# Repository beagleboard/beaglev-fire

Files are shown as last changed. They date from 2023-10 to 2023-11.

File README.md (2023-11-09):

# BeagleV-Fire

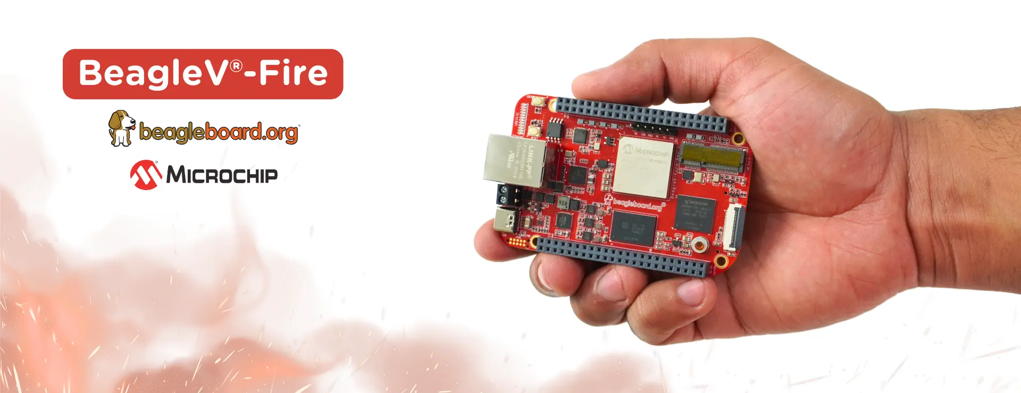
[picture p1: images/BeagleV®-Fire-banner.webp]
BeagleV® Fire banner


BeagleV®-Fire is a revolutionary SBC powered by the Microchip’s PolarFire® MPFS025T System on Chip (SoC) with 4x RV64GC Application cores, 1x RV64IMAC monitor/boot core, and FPGA fabric. BeagleV®-Fire opens up new horizons for developers, tinkerers, and the open-source community to explore the vast potential of RISC-V architecture and FPGA technology. It has the same P8 & P9 cape header pins as BeagleBone Black allowing you to stack your favourite BeagleBone cape on top to expand it’s capability. Built around the powerful and energy-efficient RISC-V instruction set architecture (ISA) along with its versatile FPGA fabric, BeagleV®-Fire SBC offers unparalleled opportunities for developers, hobbyists, and researchers to explore and experiment with RISC-V technology.

## Links

* Terms and conditions: https://docs.beagleboard.org/latest/boards/terms-and-conditions.html
* Documentation: https://docs.beagleboard.org/latest/boards/beaglev/fire
* Design: https://git.beagleboard.org/beaglev-fire/beaglev-fire
* Support: https://forum.beagleboard.org/tags/c/beaglev/15/fire
* Repair: https://www.beagleboard.org/rma
* Purchase: https://beaglev-fire.org

## Goals
* Provide a platform for developing fully open-source SoCs
* Provide solution for low-latency control, such as manufacturing machines
* Long-term availability for education

## Features
* Microchip MPFS025T-FCVG484E RISC-V based Polarfire SoC with 25k logic elements
* BeagleBone AI compatible mechanical footprint, expansion headers, serial header, buttons, LEDs and microSD slot
* 2GB LPDDR4
* 16GB eMMC
* Gigabit Ethernet
* M.2 connector and with daughterboard reference designs
  * 2.4GHz WiFi/Bluetooth using ATWILC3000 and Sub-GHz transceiver using AT86RF212B
  * USB 3 Type-A with SuperSpeed (repurpose PCIe SERDES)
* TagConnect compatible JTAG header footprint
* USB Type-C with SuperSpeed/PCIe, able to provide power
* CSI / Low-speed flexible flat cable (FFC) expansion connector
* [Support for HDMI framer board through Cape headers](https://wiki.seeedstudio.com/BeagleBone_Green_HDMI_Cape/)
* Additional power connector
* [SYZYGY high-speed expansion connector](https://syzygyfpga.io/)

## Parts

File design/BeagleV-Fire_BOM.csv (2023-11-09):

SKU | Description | Manufacturer | MPN | Location | Qty
102110898 | BeagleV - Fire
202003659 | PCBA; BeagleV-Fire |  |  |  | 1
301010000 | SMD RES 0R-5%-1/16W;0402 | YAGEO | RC0402JR-070RL | R51,R53,R66,R67,R69,R102,R151,R182,R186,R220,R221,R234,R235,R254,R262,R264,R265,R273 | 18
301010034 | SMD RES 33R-5%-1/16W;0402 | YAGEO | RC0402JR-0733RL | R159,R214 | 2
301010043 | SMD RES 1M-1%-1/16W;0402 | YAGEO | RC0402FR-071ML | R52,R226,R274,R275,R276,R277,R278,R279 | 8
301010044 | SMD RES 1K-1%-1/16W;0402 | YAGEO | RC0402FR-071KL | R15,R17,R49,R94,R95,R110,R111,R112,R113,R114,R115,R116,R120,R122,R123,R124,R125,R126,R127,R128,R129,R130,R131,R132,R133,R134,R135,R136,R137,R282 | 30
301010047 | SMD RES 10K-1%-1/16W;0402 | YAGEO | RC0402FR-0710KL | R2,R12,R13,R14,R16,R22,R23,R24,R25,R26,R27,R28,R54,R55,R56,R57,R58,R59,R60,R61,R62,R63,R99,R100,R101,R139,R150,R152,R153,R156,R161,R162,R168,R209,R210,R212,R213,R244,R245,R246,R247,R248,R255,R281 | 44
301010050 | SMD RES 510R-5%-1/16W;0402 | YAGEO | RC0402JR-07510RL | R232,R233 | 2
301010051 | SMD RES 51K-1%-1/10W;0402 | Panasonic | ERJ-2RKF5102X | R285 | 1
301010052 | SMD RES 22R-1%-1/16W;0402 | YAGEO | RC0402FR-0722RL | R18,R19,R20,R21 | 4
301010072 | SMD RES 20K-1%-1/16W;0402 | YAGEO | RC0402FR-0720KL | R117 | 1
301010081 | SMD RES 200K-1%-1/16W;0402 | YAGEO | RC0402FR-07200KL | R251 | 1
301010410 | SMD RES 1M-1%-1/4W;1206 | YAGEO | RC1206FR-071ML | R32 | 1
301010444 | SMD RES 10R-1%-1/16W;0402 | YAGEO | RC0402FR-0710RL | R72,R73,R74,R75,R76,R77,R143,R144,R147 | 9
301010456 | SMD RES 100K-1%-1/16W;0402 | YAGEO | RC0402FR-07100KL | R138,R227,R252,R253,R283,R284 | 6
301010457 | SMD RES 49.9K-1%-1/16W;0402 | YAGEO | RC0402FR-0749K9L | R1,R4,R5,R6,R7,R8,R9,R10,R11,R71,R88,R92,R93,R96,R97,R103,R140,R141,R154,R171 | 20
301010524 | SMD RES 100R-±1%-1/20W;0201 | YAGEO | RC0201FR-07100RL | R266,R267,R268,R269,R270,R271,R272 | 7
301010525 | SMD RES 0R-±1%-1/20W;0201 | YAGEO | RC0201FR-070RL | R37,R38,R105,R106,R173,R174 | 6
301010567 | SMD RES 1.5K-1%-1/16W;0402 | YAGEO | RC0402FR-071K5L | R219 | 1
301010633 | SMD RES;4.7K-1%-1/16W-0402 | YAGEO | RC0402FR-074K7L | R176,R177,R178,R187,R191,R192,R215,R216,R217,R218,R222,R223 | 12
301010671 | SMD RES 2.7K-1%-1/16W;0402 | YAGEO | RC0402FR-072K7L | R280 | 1
301010738 | SMD RES 15K-1/16W-1%;0402 | YAGEO | RC0402FR-0715KL | R107 | 1
301010746 | SMD RES 2.2K-1%-1/16W;0402 | YAGEO | RC0402FR-072K2L | R39,R108,R109,R155,R249,R250 | 6
301010783 | SMD RES 82K-1%-1/16W;0402 | YAGEO | RC0402FR-0782KL | R148 | 1
301010856 | SMD RES 2.49K-1%-1/16W;0402 | YAGEO | RC0402FR-072K49L | R118,R175 | 2
301010860 | SMD RES 124K-1%-1/16W;0402 | YAGEO | RC0402FR-07124KL | R146 | 1
301010861 | SMD RES 8.06K-1%-1/16W;0402 | YAGEO | RC0402FR-078K06L | R64 | 1
301011069 | SMD RES 240K-1/16W-1%;0402 | YAGEO | RC0402FR-07240KL | R145 | 1
301011314 | SMD RES 432K-1%-1/16W;0402 | YAGEO | RC0402FR-07432KL | R121 | 1
301011474 | SMD RES 1.1K-1%-1/16W;0402 | YAGEO | RC0402FR-071K1L | R119 | 1
301011475 | SMD RES 240R-1%-1/16W;0402 | YAGEO | RC0402FR-07240RL | R3 | 1
301011477 | SMD RES 27R-1%-1/16W;0402 | YAGEO | RC0402FR-0727RL | R48 | 1
301011831 | SMD RES 105K-1%-1/16W;0402 | YAGEO | RC0402FR-07105KL | R149 | 1
302010000 | SMD CAP Ceramic 33pF-50V-5%-NPO;0402 | YAGEO | CC0402JRNPO9BN330 | C27,C210,C214,C220 | 4
302010004 | SMD CAP Ceramic 100nF-16V-10%-X7R;0402 | YAGEO | CC0402KRX7R7BB104 | C63,C64,C65,C66,C67,C68,C69,C70,C71,C74,C75,C81,C82,C90,C93,C98,C106,C107,C109,C112,C114,C117,C120,C121,C127,C128,C134,C136,C138,C189,C201,C216,C223,C269,C281,C283,C284,C285,C287,C288,C290,C292,C298,C313,C323,C325 | 46
302010006 | SMD CAP Ceramic 10nF-50V-10%-X7R;0402 | YAGEO | CC0402KRX7R9BB103 | C209 | 1
302010010 | SMD CAP Ceramic 470pF-50V-10%-X7R;0402 | YAGEO | CC0402KRX7R9BB471 | C211 | 1
302010012 | SMD CAP Ceramic 100pF-50V-5%-NPO;0402 | YAGEO | CC0402JRNPO9BN101 | C207,C208,C226,C327,C328 | 5
302010016 | SMD CAP Ceramic 18pF-50V-5%-NPO;0402 | YAGEO | CC0402JRNPO9BN180 | C104,C105,C321,C322 | 4
302010024 | SMD CAP Ceramic 100nF-25V-10%-X7R;0402 | YAGEO | CC0402KRX7R8BB104 | C273,C274,C301,C302,C303,C304,C305,C306,C307,C308,C309,C310 | 12
302010027 | SMD CAP Ceramic 27pF-50V-5%-NPO;0402 | YAGEO | CC0402JRNPO9BN270 | C95,C96 | 2
302010039 | SMD CAP Ceramic 2.2nF-25V-10%-X7R;0402 | YAGEO | CC0402KRX7R8BB222 | C217,C218,C225 | 3
302010040 | SMD CAP Ceramic 1uF-10V-10%-X5R;0402 | YAGEO | CC0402KRX5R6BB105 | C77,C110,C111,C196,C197,C198,C199,C202,C215,C224 | 10
302010054 | SMD CAP Ceramic 2.2uF-10V-10%-X7R;0603 | YAGEO | CC0603KRX7R6BB225 | C115 | 1
302010103 | SMD CAP Ceramic 10uF-10V-10%-X5R;0603 | YAGEO | CC0603KRX5R6BB106 | C58,C59,C60,C61,C62,C119,C129,C135,C139,C185,C188,C193,C238,C242,C245,C248,C251,C318,C319,C320 | 20
302010111 | SMD CAP Ceramic 4.7uF-10V-10%-X5R;0603 | YAGEO | CC0603KRX5R6BB475 | C72,C73,C280,C282,C289,C291,C324 | 7
302010146 | SMD CAP Ceramic 4.7uF-25V-10%-X5R;0805 | YAGEO | CC0805KKX5R8BB475 | C1,C203,C219,C312 | 4
302010166 | SMD CAP Ceramic 47uF-6.3V-20%-X5R;0805 | YAGEO | CC0805MKX5R5BB476 | C146,C147,C157,C168,C169,C172,C178,C183,C194,C195,C230,C236,C259 | 13
302010235 | SMD CAP Ceramic 22uF-25V-20%-X5R;0805 | YAGEO | CC0805MKX5R8BB226 | C113,C116,C190,C191,C192,C200,C204,C205,C221,C222,C314 | 11
302010270 | SMD CAP Ceramic;1uF-6.3V-±20%-X5R;0201 | YAGEO | CC0201MRX5R5BB105 | C154,C155,C156 | 3
302010271 | SMD CAP Ceramic 100nF-10V-10%-X5R;0201 | YAGEO | CC0201KRX5R6BB104 | C2,C3,C4,C5,C6,C7,C8,C9,C10,C11,C12,C13,C14,C15,C16,C17,C18,C19,C20,C21,C22,C23,C24,C25,C26,C28,C29,C30,C31,C32,C33,C34,C35,C36,C37,C38,C39,C40,C41,C42,C43,C44,C45,C46,C48,C49,C50,C51,C52,C53,C54,C55,C56,C57,C85,C86,C87,C88,C132,C133,C144,C145,C151,C152,C153,C167,C171,C176,C177,C180,C184,C187,C206,C228,C229,C234,C235,C237,C239,C240,C241,C243,C244,C246,C247,C249,C250,C252,C257,C258,C260 | 91
302010389 | SMD CAP Ceramic 1nF-16V-10%-X7R;0201 | YAGEO | CC0201KRX7R7BB102 | C170,C173,C179,C186,C231,C232,C253 | 7
302010394 | SMD CAP Ceramic 1nF-50V-5%-X7R;0402 | YAGEO | CC0402JRX7R9BB102 | C91,C212,C213,C270 | 4
302010423 | SMD CAP Ceramic;47nF-6.3V-10%-X5R;0201 | YAGEO | CC0201KRX5R5BB473 | C148,C149,C150 | 3
302010426 | SMD CAP 2.2nF-10V-10%-X7R;0201 | YAGEO | CC0201KRX7R6BB222 | C140,C141 | 2
302010726 | SMD CAP Ceramic 3.3nF-25V-10%-X7R;0201 | Murata | GRM033R71E332KA12D | C254 | 1
302010727 | SMD CAP Ceramic 4.7nF-10V-10%-X7R;0201 | YAGEO | CC0201KRX7R6BB472 | C165,C181,C227,C233,C255 | 5
302010746 | SMD CAP Ceramic;6.8pF-50V-0.25pF-C0G-0402 | Murata | GRM1555C1H6R8CA01D | C311 | 1
302010747 | SMD CAP Ceramic 100uF-10V-20%-X5R;1206 | TDK | C3216X5R1A107M160AC | C108 | 1
302011831 | SMD CAP Ceramic 10nF-6.3V-10%-X5R;0201 | Yageo | CC0201KRX5R5BB103 | C142,C143,C160,C161,C162,C163,C164,C166,C174,C175,C182,C256 | 12
302011962 | SMD CAP Ceramic 1nF-2kV-10%-X7R;1206 | YAGEO | CC1206KKX7RDBB102 | C83 | 1
302020469 | SMD CAP Tantalum 330uF-2.5V;B | KEMET | T520B337M2R5ATE070 | C158,C159 | 2
303010128 | SMD Inductor 2.2uH-20%-1.3A;2P-2520 | Murata | LQM2HPN2R2MG0L | L5 | 1
303010172 | SMD Innductor 0.47uH-20%;L2.0*W1.6*H1.0mm | Sunlord | WPN201610MR47MT | L2,L3,L4 | 3
303011528 | SMD Power Inductor 0.56uH-20%-9.3A;2P-4.4*4.4*1.9MM | CODACA | CSHB0421-R56M | L1 | 1
303011879 | SMD Inductor 1.0uH-20%-7A;L4.2*W4.4*H2.0mm | Sunlord | MWSA0402S-1R0MT | L6 | 1
303030040 | SMD Ferrite Bead 120R-1.3A;0402 | Murata | BLM15PD121SN1D | FB3,FB4 | 2
304011072 | SMD Diode Schottky 30V-200mA;SOD-523 | LRC | LRB520S-30T1G | D15,D16,D17 | 3
304050002 | SMD Diode TVS 5V-600W;DO-214AA | ST | SMBJ5.0CA-TR | D8 | 1
304051161 | SMD Diode TVS 24VWM 29.5V;SMB | Brightking | SMBJ24CA(Brightking) | D25 | 1
304060074 | SMD Diode ESD 0.05pF;0402 | SEMITEL | ESDPSA0402V05 | D3,D4,D5,D6,D7,D9,D10,D11,D12,D13,D14,D18,D19 | 13
304060294 | SMD Diode Array ESD;4 Channel | TI | TPD4E05U06DQAR | D1,D2 | 2
304090075 | SMD LED Clear-Blue;0402 | Bright | BL-HB337A-AV-TRB | LED3,LED4,LED5,LED6,LED7,LED8,LED9,LED10,LED11,LED12,LED13,LED14 | 12
304090121 | SMD LED Clear-Green;0402 | Bright | BL-HGE37A-AV-TRB | LED1 | 1
305020002 | SMD Transistors PNP 40V-200mA;SOT-23 | ON | MMBT3906LT3G | Q30 | 1
305030659 | SMD MOSFET N-CH 20V -630MA ；SOT-523 | Diodes | DMG1012T-7 | Q3,Q4,Q5,Q6,Q7,Q8,Q9,Q10,Q11,Q12,Q13,Q14,Q15,Q16,Q19,Q20,Q24,Q25,Q27,Q28 | 20
305031179 | SMD MOSFET P-CH 30V-12A;HSMT8 | Rohm | RQ3E120ATTB | Q1,Q17,Q29,Q31 | 4
305050191 | SMD Transistor Array 2PNP 45V-0.1A;SOT36 | Diodes Incorporated | BCM857BS-7-F | Q18,Q2 | 2
306011049 | SMD Crystal;25MHz-18pF-20ppm;SMD-2520-4P-L2.5*W2.0*H0.6mm | Interquip | 5ZAA25000182TFA0Q3 | X1 | 1
306011142 | SMD Crystal 27MHZ-12PF-30ppm;4P-L2.5*W2.0*H0.6mm | Interquip | 5ZAA27000121TF60Q3 | X2 | 1
306011268 | SMD Crystal 25MHz-12pF-10ppm-30ppm-50R;4P-SMD-L3.2*W2.5*H0.8mm | Interquip | 5YAA25000121TF50Q3 | X3 | 1
306020621 | SMD Oscillator;32.768KHz-3.3V-30ppm;SMD-2520-4P-L2.5*W2.0*H0.95mm | Interquip | 1651-L3273-BTBQYA | OSC1 | 1
306020701 | SMD Oscillator;125MHz-10ppm-6P-3.2*2.5mm | Microchip | DSC1123CI5-125.0000 | U7 | 1
310011580 | SMD IC PHY;10/100/1000 Ethernet Physical Layer Transceiver With RGMIII and SGMII;QFN-48 | Realtek | RTL8211FS-CG | U28 | 1
310030211 | SMD IC PMIC;MSOP-8 | TI | TPS2051BDGNR | U10 | 1
310031388 | SMD IC PMIC; IC VREF SHUNT ADJ;SOT23-3 | TI | ATL431AIDBZR | U39 | 1
310031449 | SMD IC PMIC;SOT23-5 | TI | TLV62569DBVT | U36 | 1
310032350 | SMD IC PMIC;10A-QFN-32 | Microchip | MIC22950YML-TR | U13 | 1
310032351 | SMD IC PMIC LDO-3.3V-150mA;SOT-23A | Microchip | MCP1754ST-3302E/CB | U16 | 1
310032353 | SMD IC PMIC;3A-DFN-12 | Microchip | MIC23303YML-TR | U18,U19,U20 | 3
310032372 | SMD IC PMIC LDO-ADJ-500mA;DFN-8 (2x3mm) | Microchip | MCP1725T-ADJE/MC | U17 | 1
310050078 | SMD IC Logic;US8(8-VFSOP | TI | SN74LVC2G241DCUR | U21 | 1
310051370 | SMD IC Logic;4-Bit Bidirectional Voltage-Level Translator;DSBGA-12 | Union Semiconductor | UM3304 | U30,U31,U32,U33,U34,U35 | 6
310071169 | SMD IC Interface;QFN-32 | Microchip | USB3340-EZK-TR | U8 | 1
310071170 | SMD IC Controller;X2QFN12 | NXP | PTN5150AHXMP | U9 | 1
310091085 | SMD IC Memory;16GB eMMC 5.1;VFBGA-153 | Kingston | EMMC16G-TB29-PZ90 | U3 | 1
310091104 | SMD IC Memory;SOIC-8 | Winbond | W25Q128JVSIQ | U4 | 1
310091347 | SMD IC Memory;32Kb-IIC Serial EEPROM;SOT23-5 | FMD | FT24C32A-ELRT | U22 | 1
310091407 | SMD IC Memory;LPDDR4 2GB(16bits x 2 channels) 1866MHz 3733Mbps;FBGA-200 (10X15) | Samsung | K4F6E3S4HM-MGCJ | U2 | 1
310100567 | SMD IC ADC 16-BIT SPI;UQFN-20 | Microchip | MCP3464RT-E/NC | U11 | 1
310110523 | SMD IC Clock;PCI-Express Gen 2 Dual Output 100MHz Clock Generator;TDFN-10 | Skyworks | Si52112-B3-GM2 | U38 | 1
310990589 | SMD IC REG LINEAR 2.5V 300MA;SOT23-5 | Microchip | MIC5504-2.5YM5-TR | U14 | 1
310991057 | SMD IC FPGA SoC;FCVG-484 | Microchip | MPFS025T-FCVG484E | U1 | 1
311020518 | SMD Top Button 1.57N;4P-L4.6*W3.2*H2.5mm | ALPS | SKRPABE010 | SW1,SW2 | 2
319015079 | PCB;BeagleV-Fire Rev A-Red-12 Layers |  |  |  | 1
320010943 | SMD USB Type-c;12P+4-8.9*7.3*3.2mm | MTCONN | UBF31-0171 | J5 | 1
320020078 | DIP Black Male Header VERT;1*6P-2.54-2.5-11.5/3.0mm | Sinotop | ST-PH-254-0087-1*6P-6T | J6 | 1
320030424 | DIP Black Female Header;2*23P-2.54*8.5-3.0mm | Sinotop | FF-1236 | P8,P9 | 2
320060764 | SMD FPC CONN;22P-0.5mm-90D-Bottom Contact-L15.40*W5.25*H2.00mm | BEST | 0.5K-DX-22PWB | J7 | 1
320090416 | SMD SD Card Holder;Reverse-Bottom | YU LIANG | YL004-030-001 | J2 | 1
320111630 | SMD Connector Black m.2 E-key;67P-0.5mm | FOXCONN | AS0BC27-S40BE-7H | J9 | 1
320111970 | DIP Female Screw Terminal;2P-3.5mm-Black | Sinotop | STP128-350-2P | J1 | 1
320140517 | DIP RJ45;1000M | LINK-PP | LPJG0933H11NL | J4 | 1
320210541 | SMD BTB Female CONN;With High Speed Differential Pair and 2*20P+2P-0.5mm;L21.27*W7.49*H3.25mm | Samtec | QSH-020-01-F-D-DP-A-K-TR | J8 | 1
326050927 | SMD Stud;M2铜柱 | FOXCONN | 2E0BC21-A40TP-7H | MH4 | 1

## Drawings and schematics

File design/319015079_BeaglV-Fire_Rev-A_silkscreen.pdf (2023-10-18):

# Ethernet LED(14-3) USB JTAG

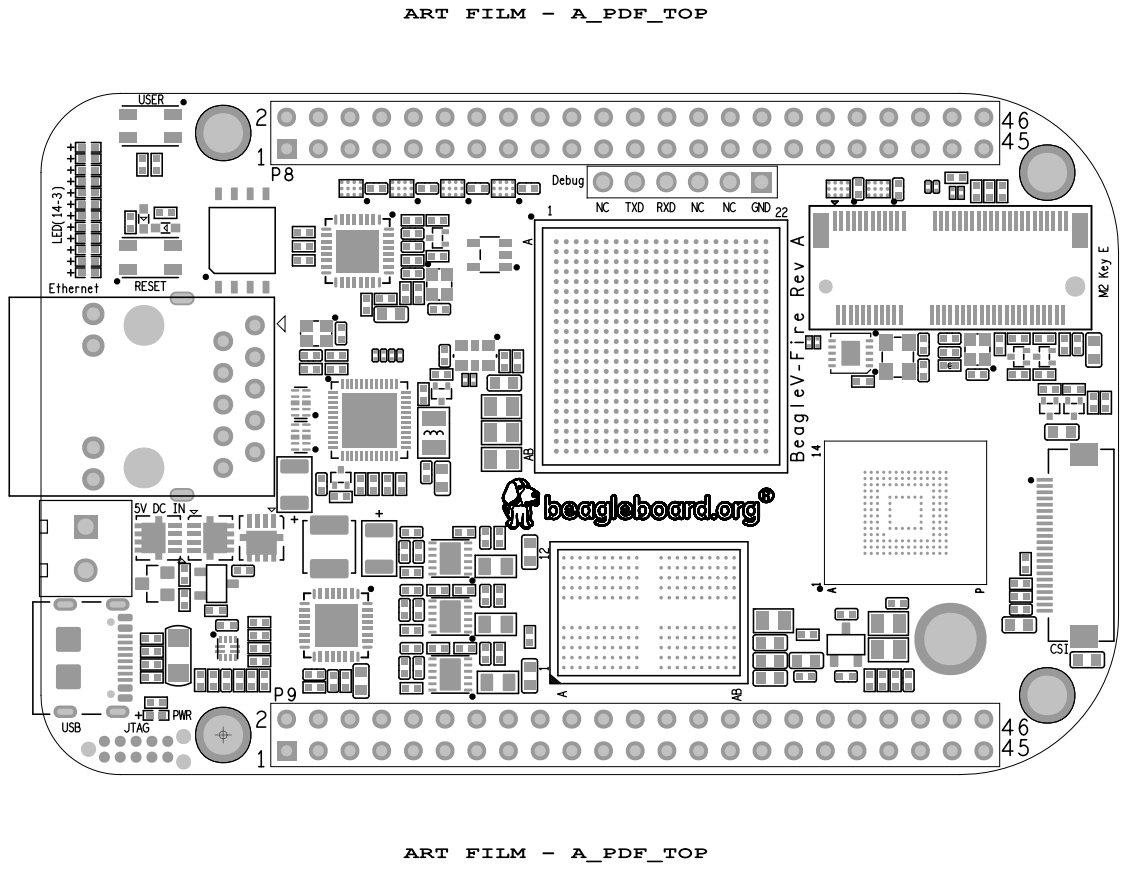
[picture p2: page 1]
ART FILM - A_PDF_TOP; RESET; PWR; USER; Debug; NC GND22; CSI; M2 Key E

NC TXD RXD NC

BeagleV-Fire Rev A

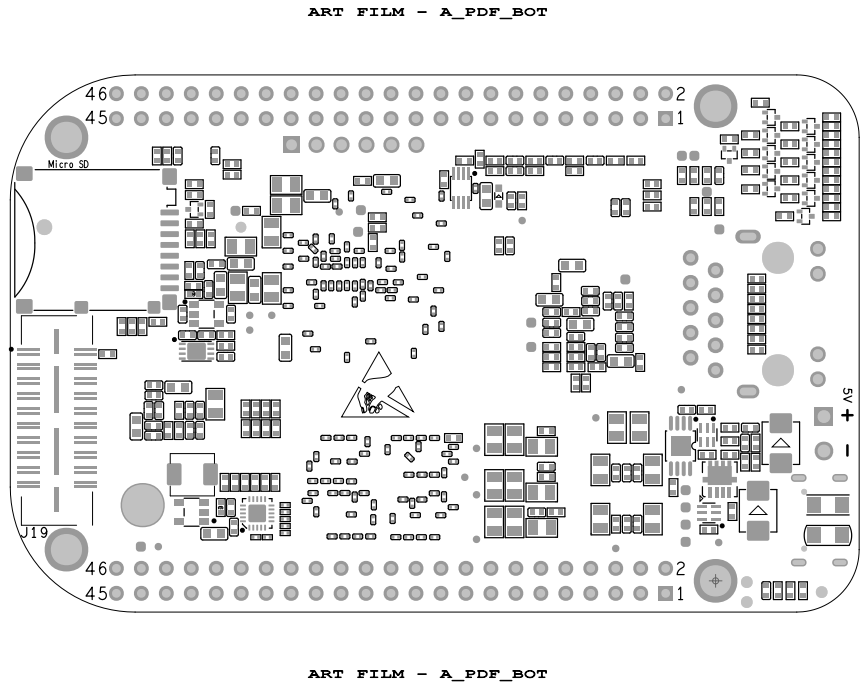
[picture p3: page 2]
ART FILM - A_PDF_BOT; Micro SD

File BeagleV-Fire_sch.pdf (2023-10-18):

# Power Supply

# Revision History

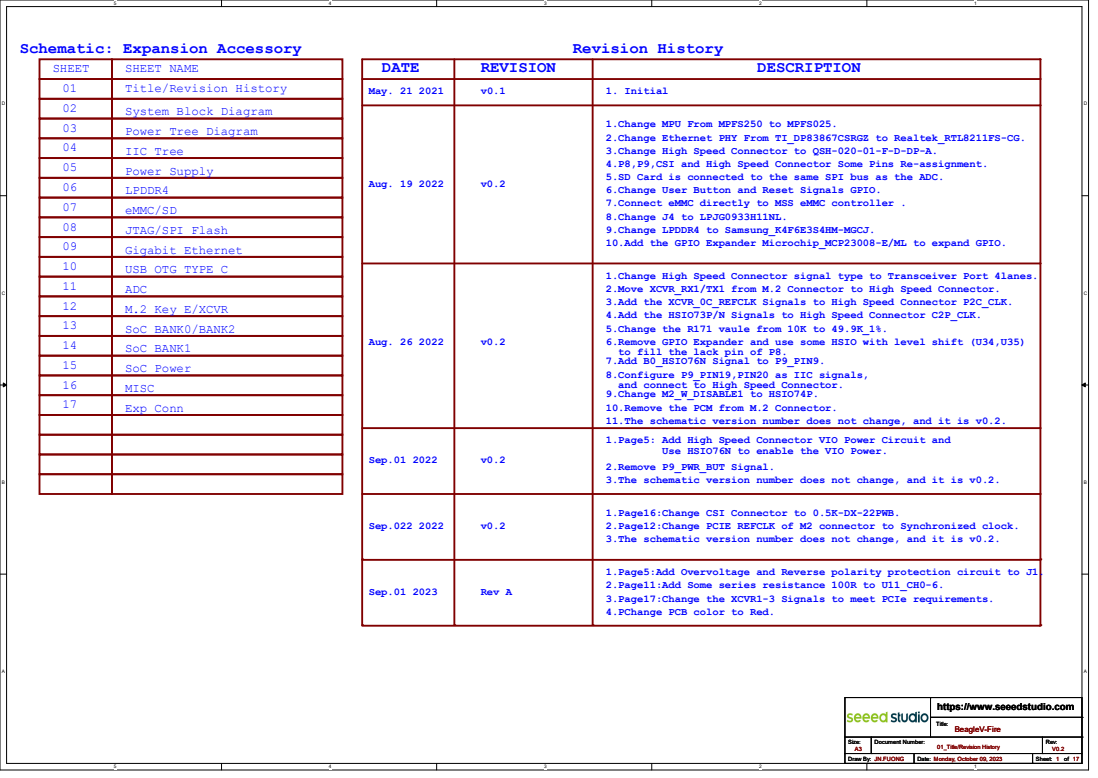
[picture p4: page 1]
May. 21 2021; 1. Initial; Schematic: Expansion Accessory; DATE; REVISION; DESCRIPTION; SHEET; Aug. 19 2022; Aug. 26 2022; 17 Exp Conn; Sep.01 2022; 4.PChange PCB color to Red.; Title: Size:; Document Number:; Rev: Draw By:; Date:; Sheet:; https://www.seeedstudio.com A3; JN.FUONG; Monday, October 09, 2023; BeagleV-Fire 01_Title/Revision History Title: Size:

SHEET NAME
Title/Revision History
System Block Diagram
Power Tree Diagram
IIC Tree

1.Change MPU From MPFS250 to MPFS025.
2.Change Ethernet PHY From TI_DP83867CSRGZ to Realtek_RTL8211FS-CG.
3.Change High Speed Connector to QSH-020-01-F-D-DP-A.
4.P8,P9,CSI and High Speed Connector Some Pins Re-assignment.
5.SD Card is connected to the same SPI bus as the ADC.
6.Change User Button and Reset Signals GPIO.
7.Connect eMMC directly to MSS eMMC controller .
8.Change J4 to LPJG0933H11NL.
9.Change LPDDR4 to Samsung_K4F6E3S4HM-MGCJ.
10.Add the GPIO Expander Microchip_MCP23008-E/ML to expand GPIO.

LPDDR4
eMMC/SD
JTAG/SPI Flash
Gigabit Ethernet
USB OTG TYPE C
ADC
M.2 Key E/XCVR
SoC BANK0/BANK2
SoC BANK1
SoC Power
MISC

1.Change High Speed Connector signal type to Transceiver Port 4lanes.
2.Move XCVR_RX1/TX1 from M.2 Connector to High Speed Connector.
3.Add the XCVR_0C_REFCLK Signals to High Speed Connector P2C_CLK.
4.Add the HSIO73P/N Signals to High Speed Connector C2P_CLK.
5.Change the R171 vaule from 10K to 49.9K_1%.
6.Remove GPIO Expander and use some HSIO with level shift (U34,U35)
to fill the lack pin of P8.
7.Add B0_HSIO76N Signal to P9_PIN9.
8.Configure P9_PIN19,PIN20 as IIC signals,
and connect to High Speed Connector.
9.Change M2_W_DISABLE1 to HSIO74P.
10.Remove the PCM from M.2 Connector.
11.The schematic version number does not change, and it is v0.2.
1.Page5: Add High Speed Connector VIO Power Circuit and

Use HSIO76N to enable the VIO Power.

2.Remove P9_PWR_BUT Signal.
3.The schematic version number does not change, and it is v0.2.

Sep.022 2022 | v0.2 | 1.Page16:Change CSI Connector to 0.5K-DX-22PWB. 2.Page12:Change PCIE REFCLK of M2 connector to Synchronized clock. 3.The schematic version number does not change, and it is v0.2.

Sep.01 2023 | Rev A | 1.Page5:Add Overvoltage and Reverse polarity protection circuit to J1. 2.Page11:Add Some series resistance 100R to U11_CH0-6. 3.Page17:Change the XCVR1-3 Signals to meet PCIe requirements.

BeagleV-Fire 01_Title/Revision History

# 8CH ADC

MIPI CSI | BeagleBoard headers

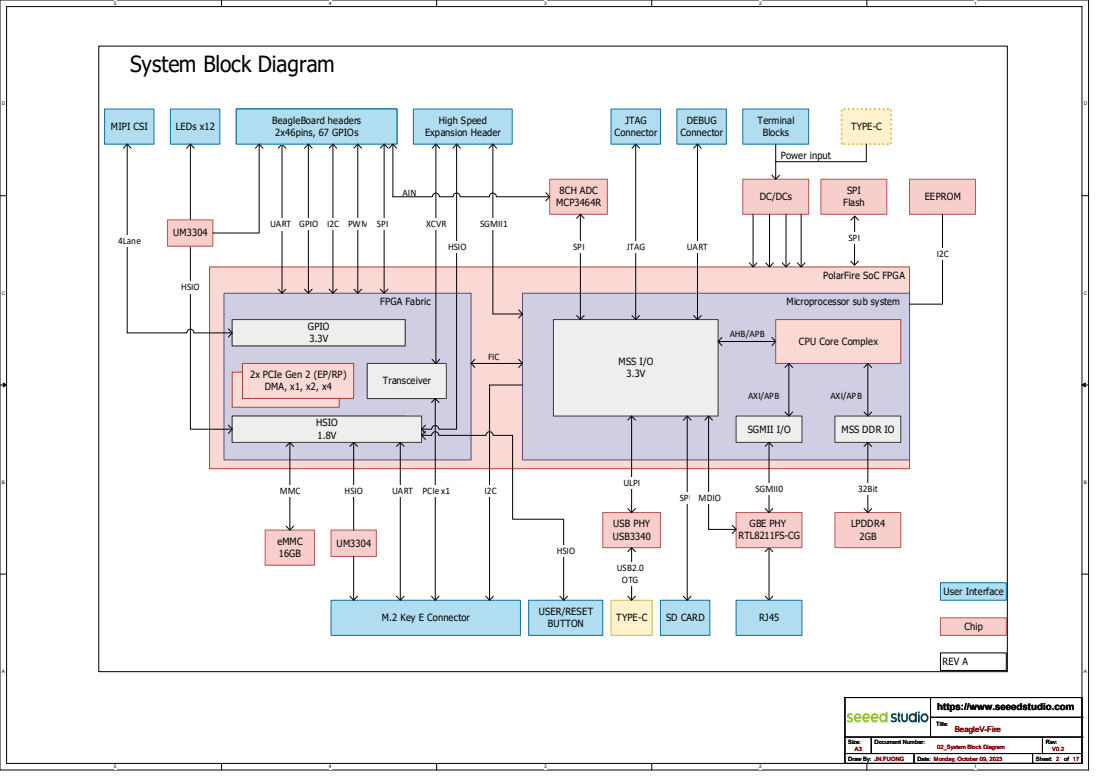
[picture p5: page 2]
SGMII I/O; MSS I/O 3.3V; LPDDR4 2GB; GBE PHY RTL8211FS-CG; USB PHY USB3340; TYPE-C; MCP3464R; HSIO; GPIO; FPGA Fabric; 2x46pins, 67 GPIOs; Transceiver; High Speed Expansion Header; eMMC 16GB; HSIO 1.8V; GPIO 3.3V; DC/DCs; Terminal; Blocks LEDs x12; JTAG Connector; DEBUG Connector; User Interface; Chip; REV A; 4Lane; BeagleBoard headers 2x46pins, 67 GPIOs; MMC; UART; XCVR; SGMII1; PCIe x1; FIC; AIN; SPI; JTAG; Power input; USB2.0 OTG; ULPI; SPI MDIO; SGMII0; 32Bit; AHB/APB; AXI/APB; SPI Flash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

System Block Diagram

GPIO I2C PWM SPI
UART

PolarFire SoC FPGA

Microprocessor sub system

CPU Core Complex

2x PCIe Gen 2 (EP/RP)
DMA, x1, x2, x4

MSS DDR IO

BUTTON M.2 Key E Connector

SD CARD USER/RESET

BeagleV-Fire 02_System Block Diagram

Reverse & OVP | USB_5V | SYS_5V

## VDD_5V

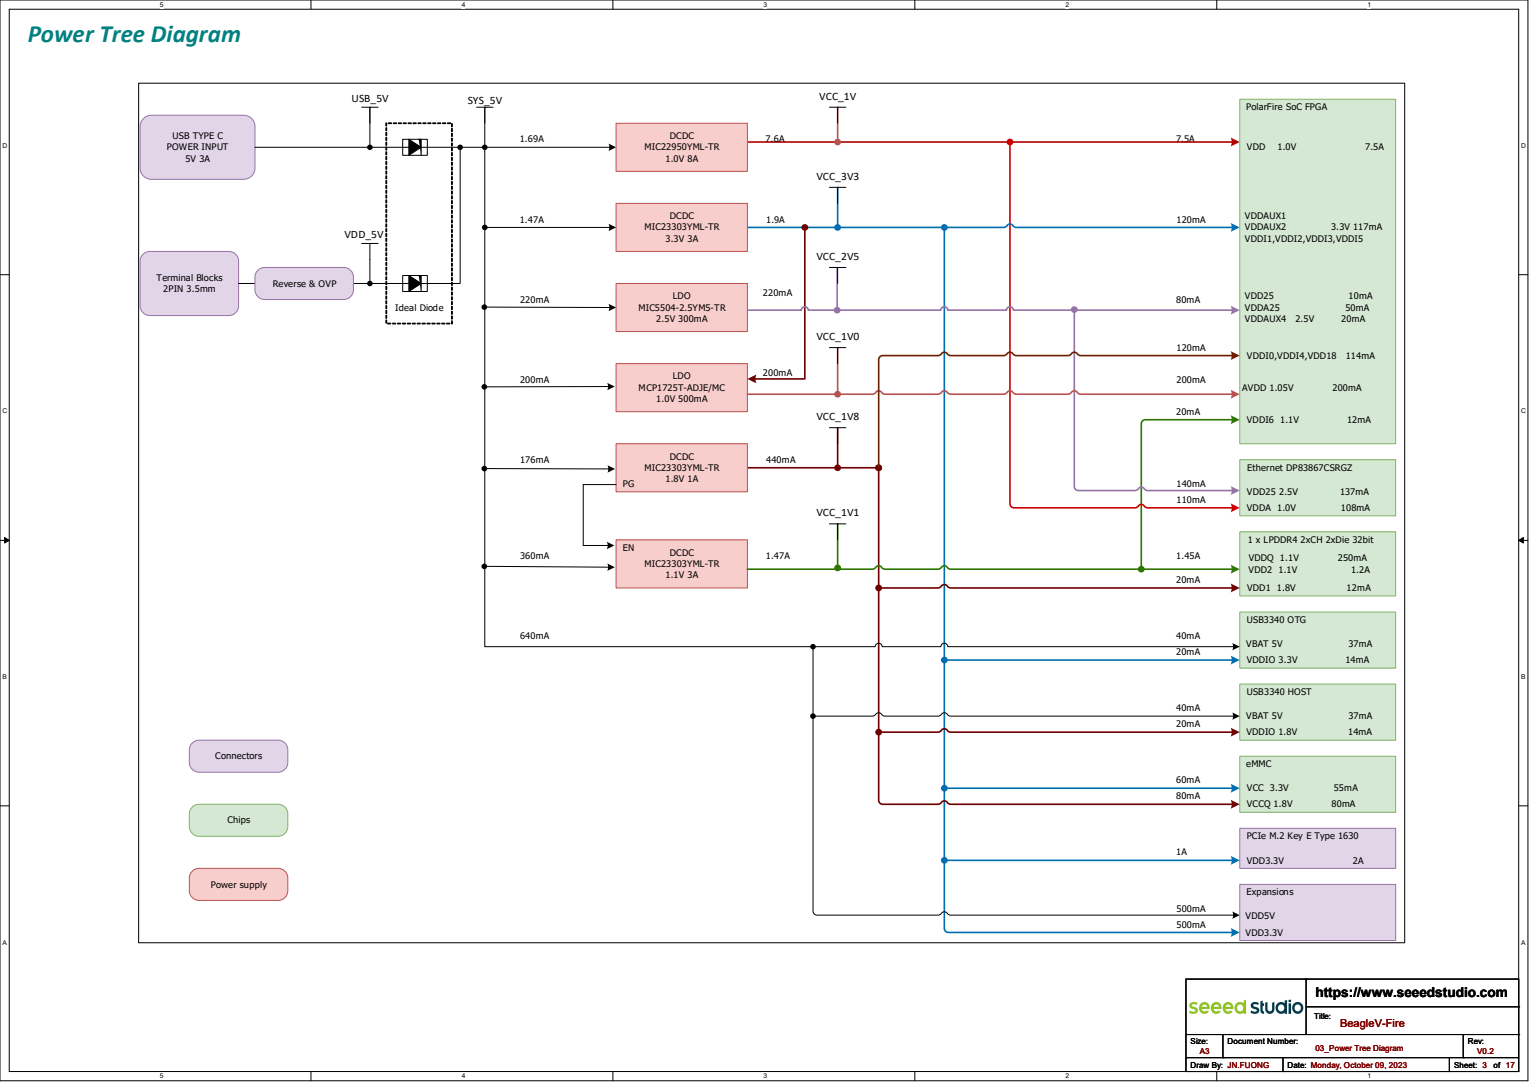
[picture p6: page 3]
USB TYPE C POWER INPUT 5V 3A; VDD 1.0V; VDDI0,VDDI4,VDD18 114mA; VDDAUX1 VDDAUX2; VDDI1,VDDI2,VDDI3,VDDI5 AVDD 1.05V; VDDI6 1.1V; 1 x LPDDR4 2xCH 2xDie 32bit VDDQ 1.1V; 250mA VDD2 1.1V; VDD1 1.8V; Ethernet DP83867CSRGZ VDDA 1.0V; VDD25 2.5V; 137mA USB3340 OTG; VBAT 5V; eMMC; VCC 3.3V; Expansions VDD5V VDD3.3V VCCQ 1.8V; VDD25; VDDA25; VDDAUX4 2.5V; VDDIO 3.3V; 14mA USB3340 HOST VBAT 5V; VDDIO 1.8V; PCIe M.2 Key E Type 1630 VDD3.3V; DCDC MIC22950YML-TR; 1.0V 500mA DCDC MIC23303YML-TR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

Power Tree Diagram

PolarFire SoC FPGA

LDO MCP1725T-ADJE/MC

BeagleV-Fire 03_Power Tree Diagram

# EEPROM ADDR:0x50

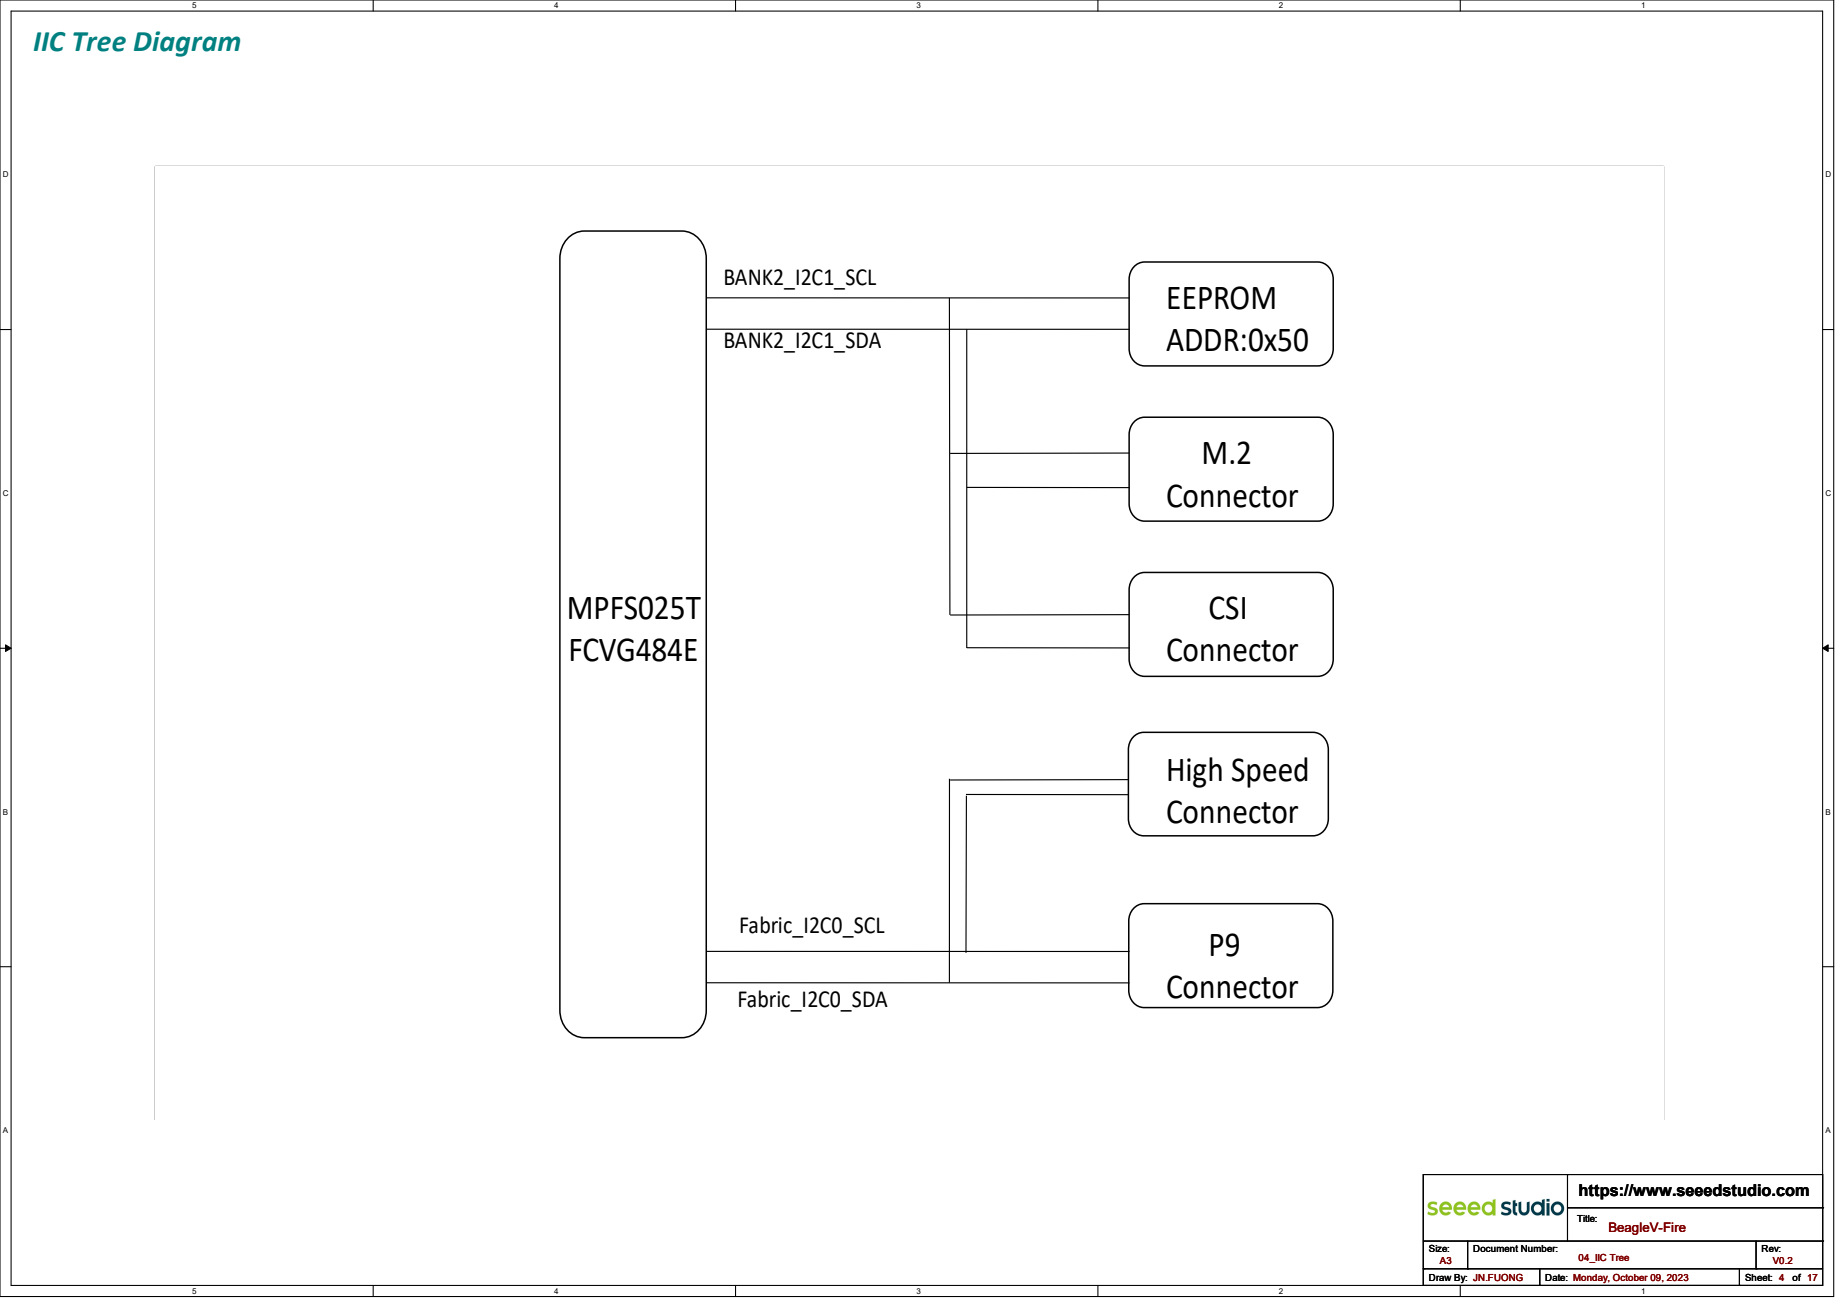
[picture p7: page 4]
MPFS025T FCVG484E; M.2 Connector; CSI Connector; High Speed Connector; P9 Connector; BANK2_I2C1_SCL; BANK2_I2C1_SDA; Fabric_I2C0_SDA; Fabric_I2C0_SCL; https://www.seeedstudio.com A3; JN.FUONG; Monday, October 09, 2023; BeagleV-Fire 04_IIC Tree Title: Size:; Document Number:; Rev: Draw By:; Date:; Sheet:

IIC Tree Diagram

BeagleV-Fire 04_IIC Tree

# VCC_3V3

# 50V Q2B

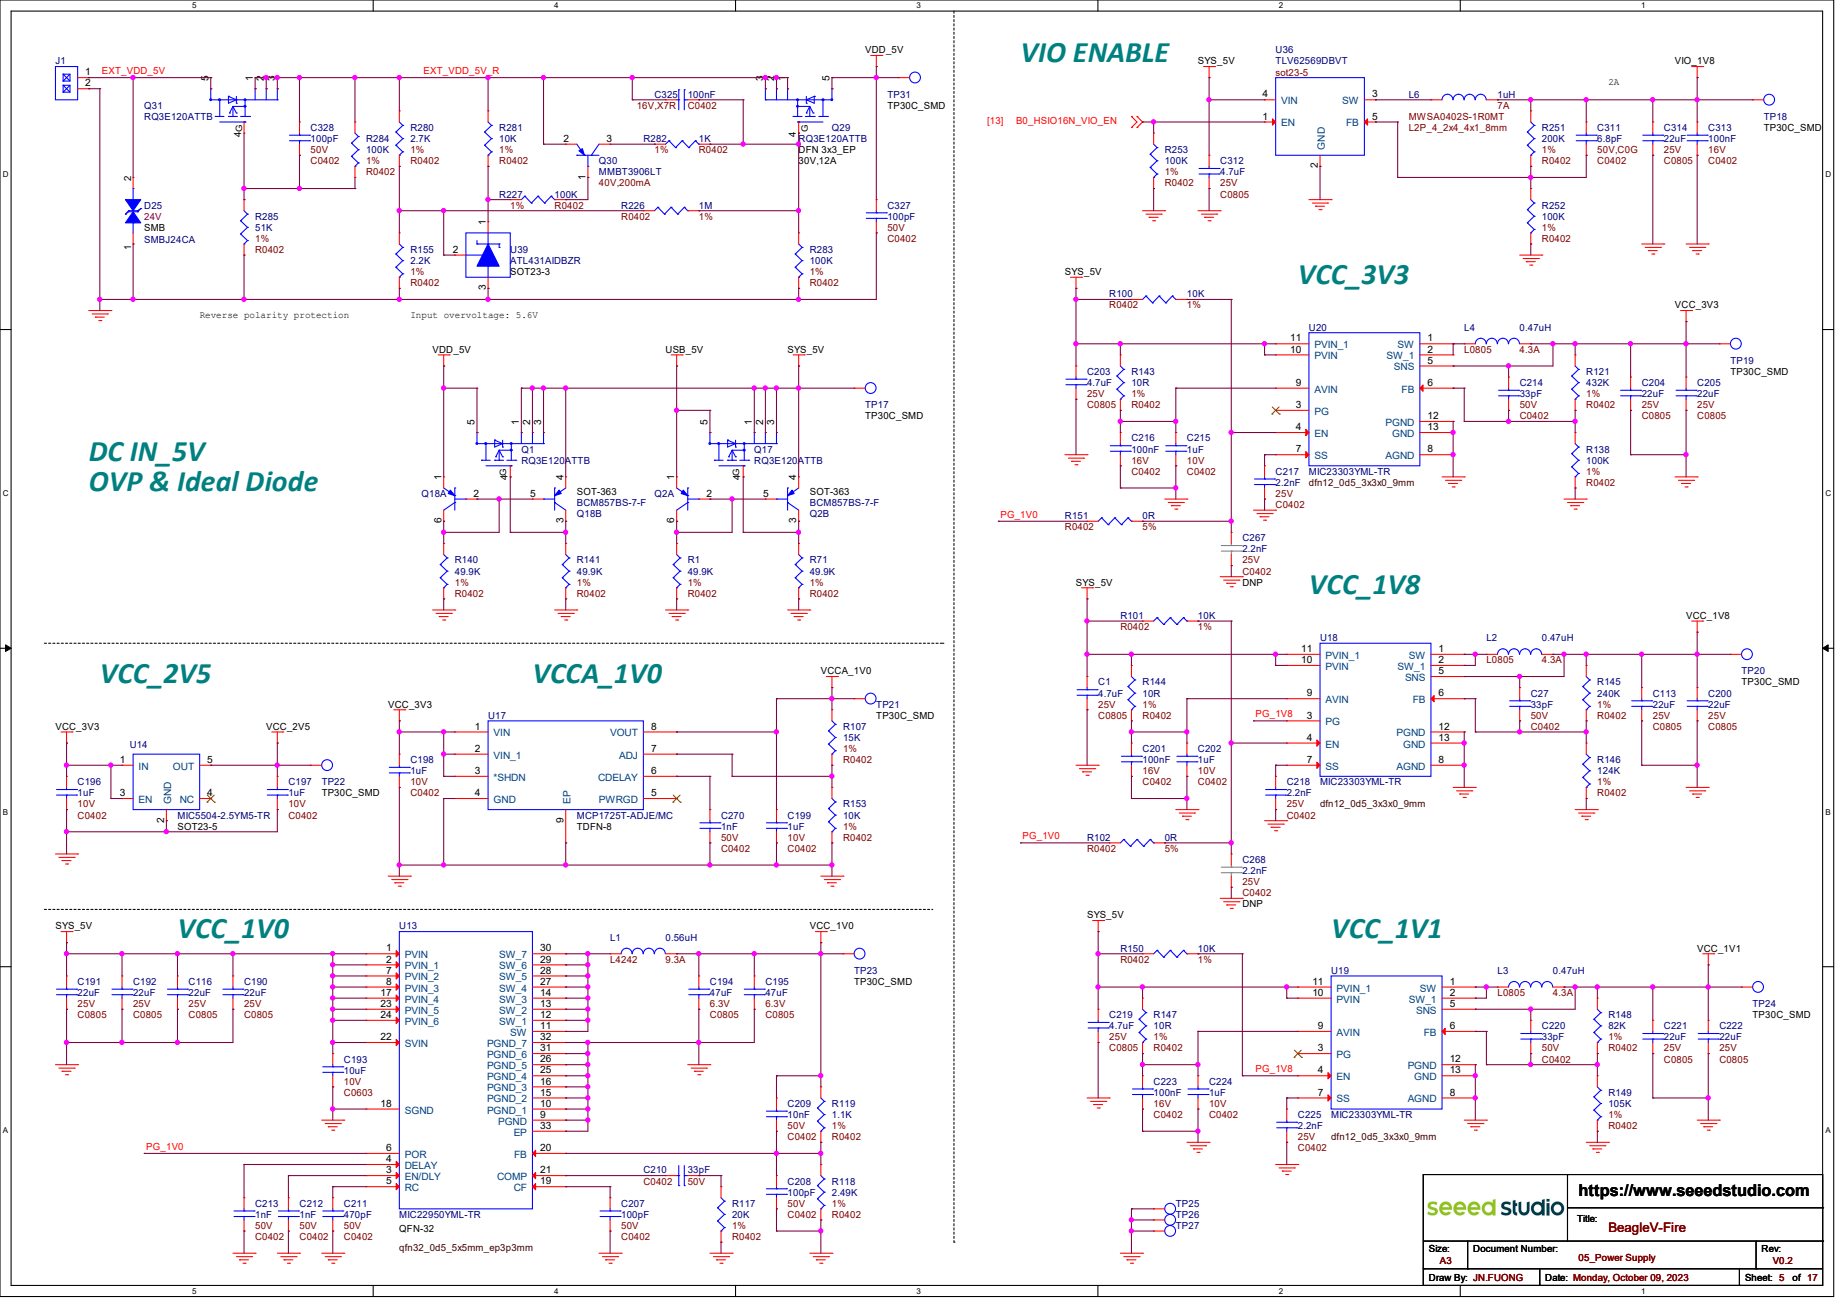
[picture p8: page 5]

# LPDDR4_CONNECTION

# VCC_1V1 VCC_1V8

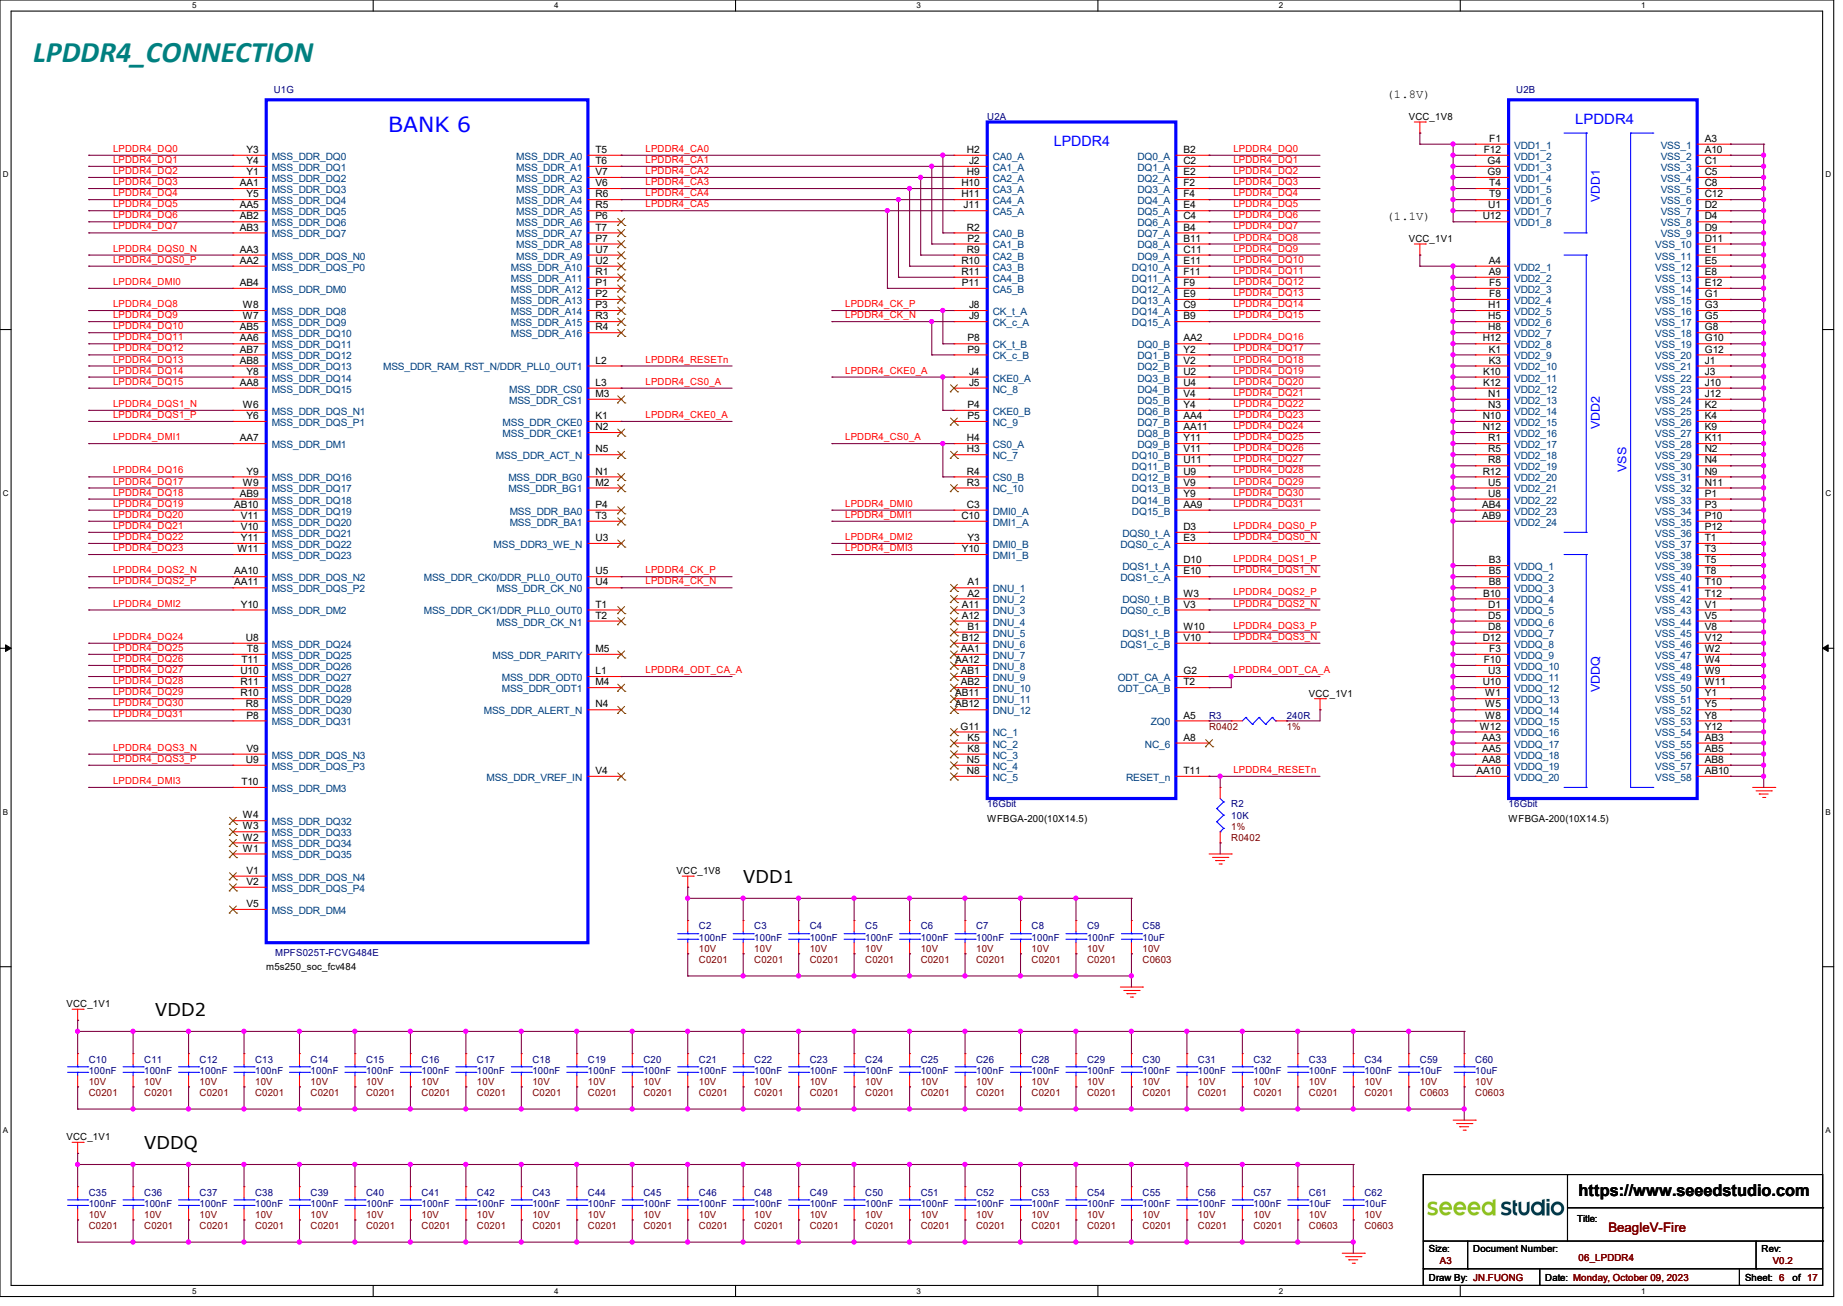
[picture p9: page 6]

# eMMC/SD

# eMMC

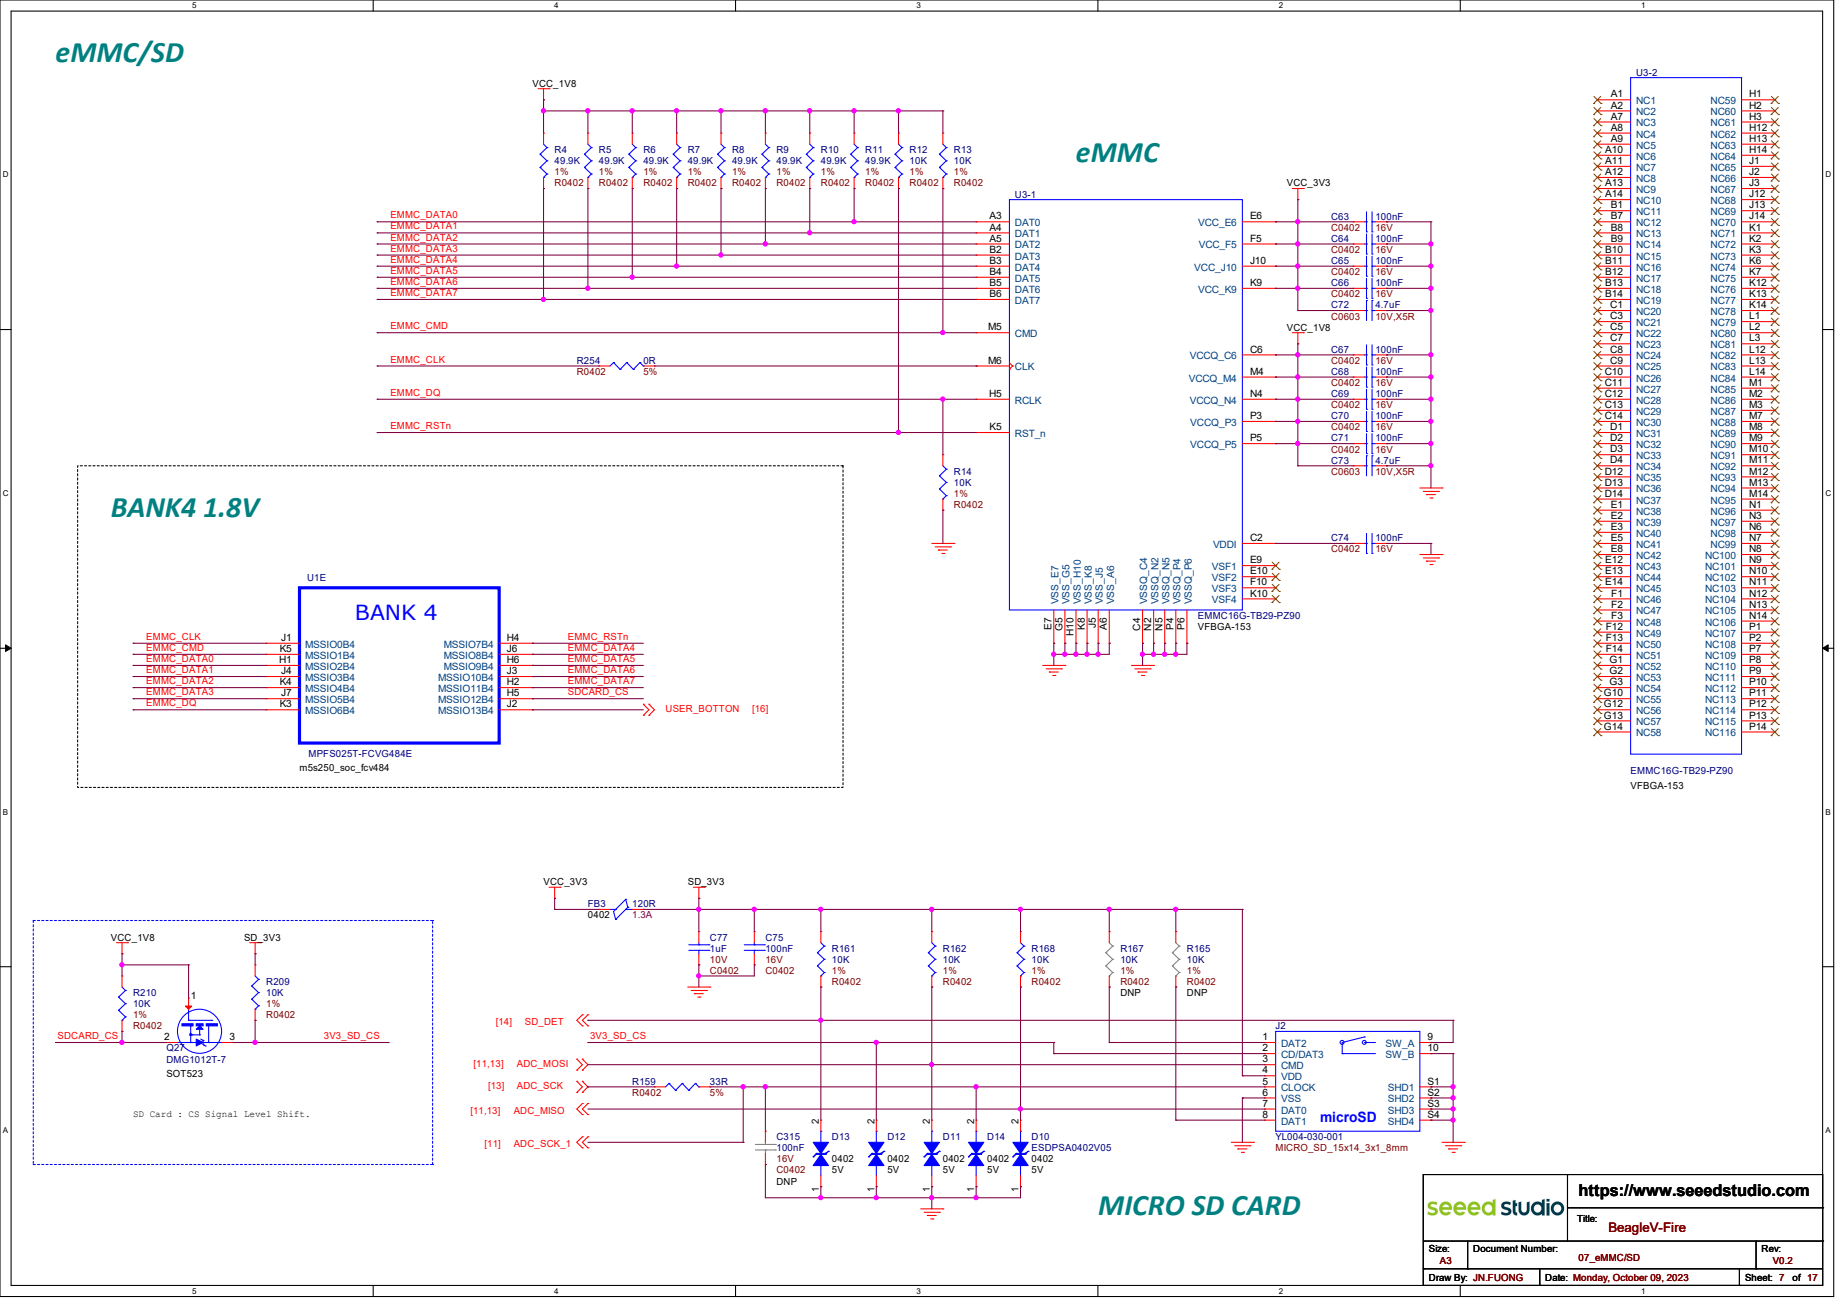
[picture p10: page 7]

MICRO SD CARD SD Card : CS Signal Level Shift.
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

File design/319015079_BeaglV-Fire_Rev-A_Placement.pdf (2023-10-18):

# ART FILM - ASSEM_TOP

# C274 U31C215

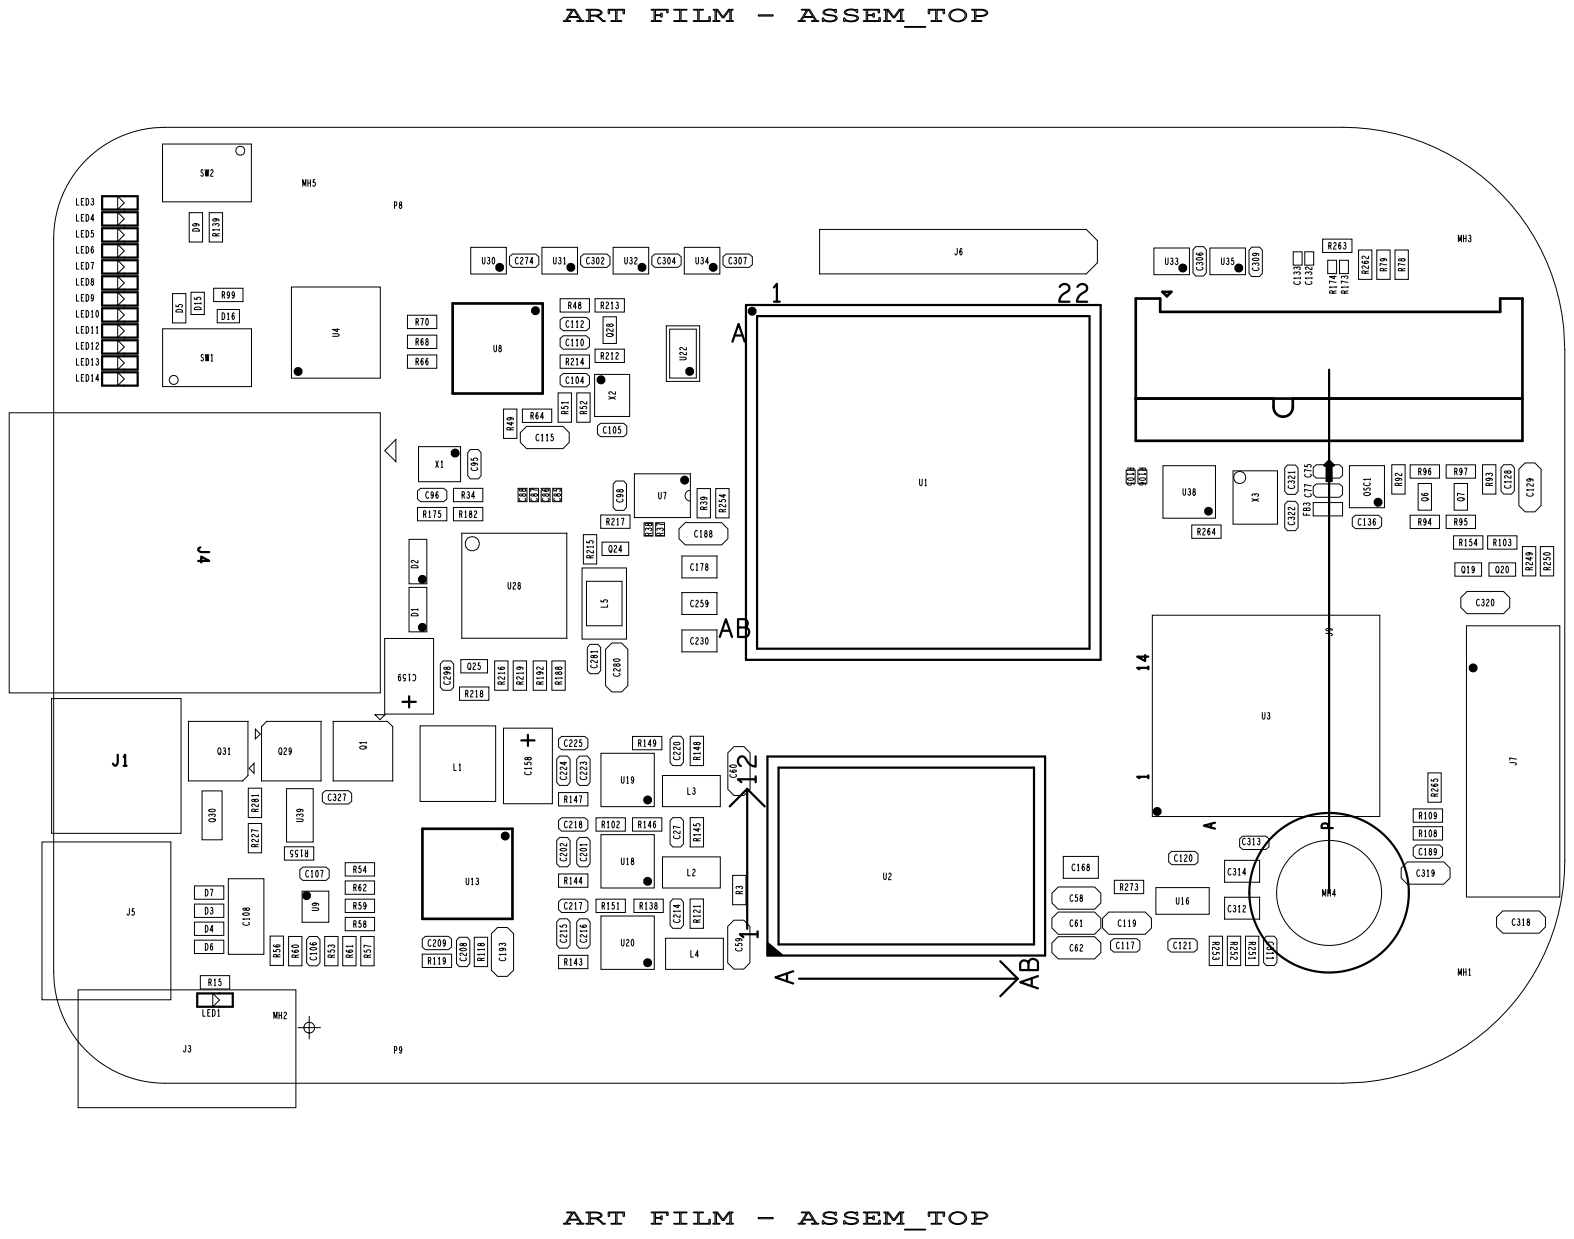
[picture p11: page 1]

# ART FILM - ASSEM_BOT

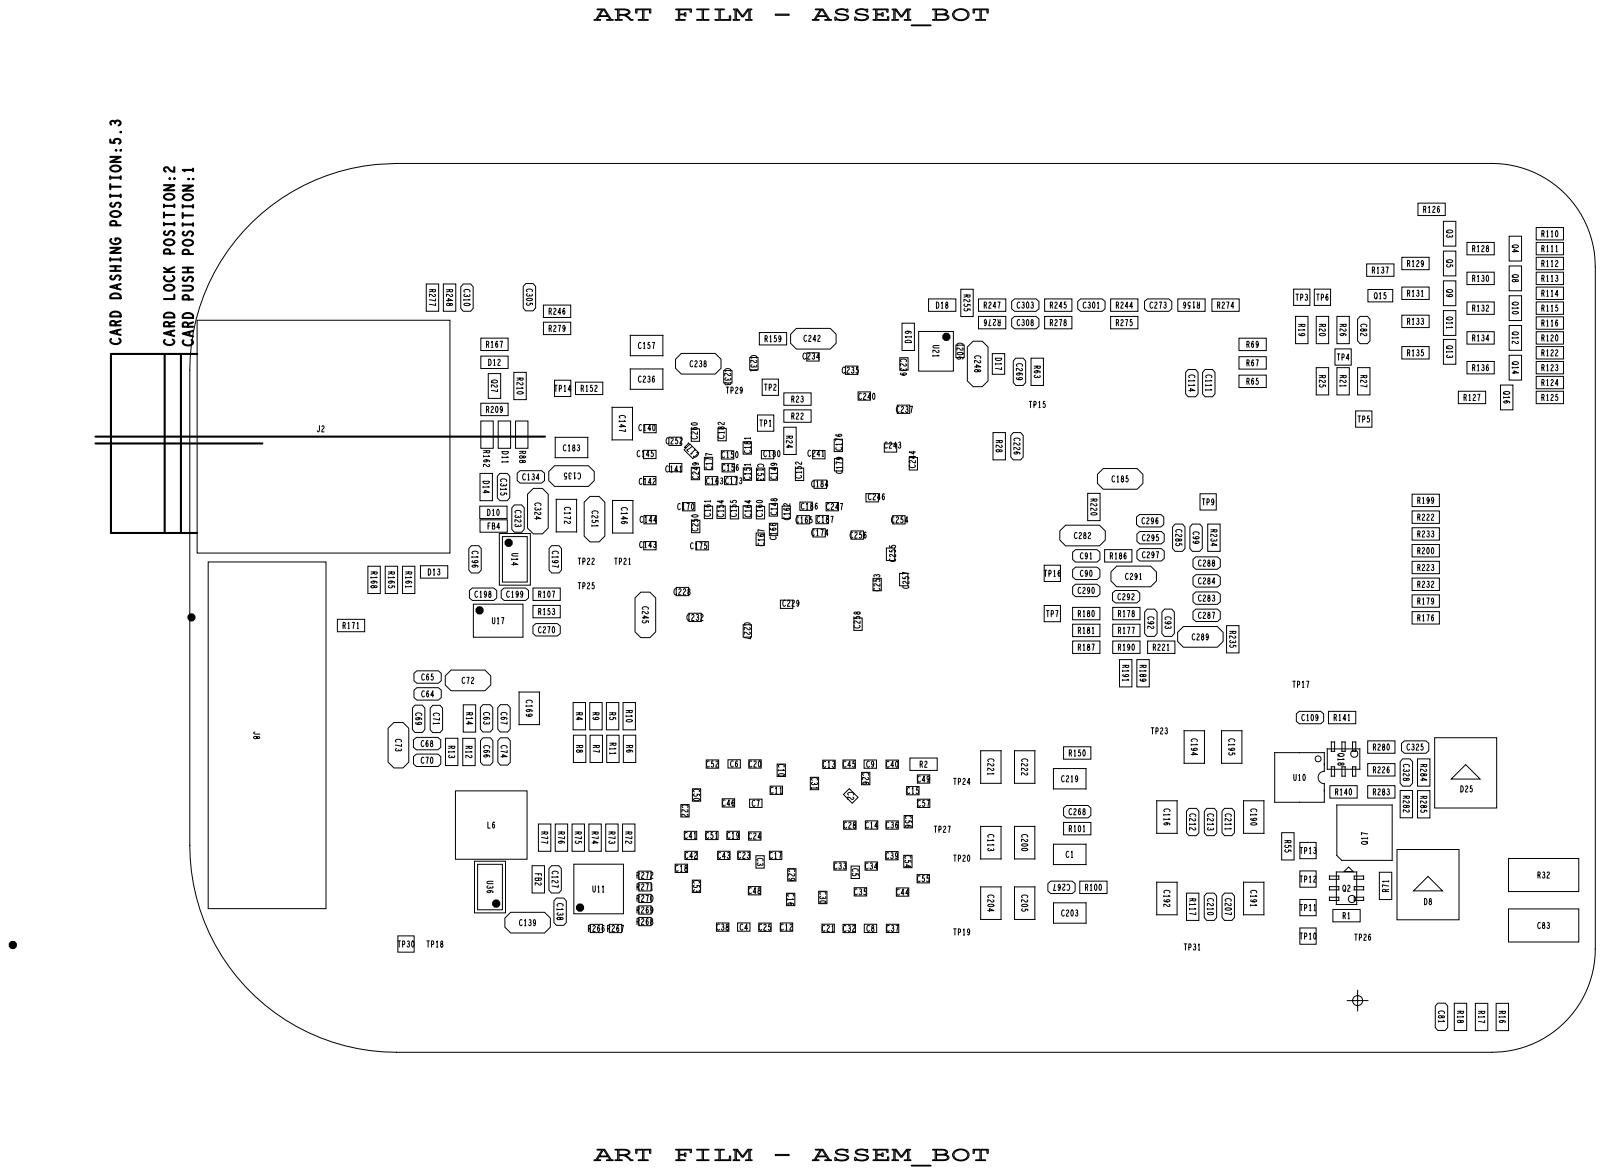
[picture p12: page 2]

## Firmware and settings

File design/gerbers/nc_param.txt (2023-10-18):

INTEGER-PLACES         2
DECIMAL-PLACES         5
X-OFFSET               0.000000
Y-OFFSET               0.000000
FEEDRATE               1
COORDINATES            ABSOLUTE
OUTPUT-UNITS           ENGLISH
TOOL-ORDER             INCREASING
REPEAT-CODES           YES
SUPPRESS-LEAD-ZEROES   YES
SUPPRESS-TRAIL-ZEROES  NO
SUPPRESS-EQUAL         NO
TOOL-SELECT            YES
OPTIMIZE_DRILLING      NO
ENHANCED_EXCELLON      YES
HEADER                 none
LEADER                 12
CODE                   ASCII
SEPARATE               NO
SEPARATE-ROUTING       NO
DRILLING               LAYER-PAIR
BACKDRILL              NO
CAVITY                 NO
COUNTER                NO
TOLERANCE_DRILL        NO
TOLERANCE_TRAVEL       NO
TOOL_SIZE              NO
ROTATION               NO
NON_STANDARD           NO
TOTAL_DRILL            NO
SEPARATE_SLOT          NO
SUPPRESS_TOLERANCE     NO
SUPPRESS_TOOLSIZE      NO
SUPPRESS_ROTATION      NO

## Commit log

2021-05-10 add PolarFire SoC MSS Configurator default output
    [polarbone.cfg]
2022-04-19 rename schematic
2022-08-11 Add updated schematic
2023-09-27 Add board gerber files (without logo and name)
    [art_param.txt, nc_param.txt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]
2023-09-27 Move beta boards schematic files
2023-09-27 Rev A design files (brd without logo and name)
    [BEAGLEV FIRE_REV A_230911.DSN]
2023-09-28 Remove unused FPGA/HSS config
    [polarbone.cfg]
2023-09-28 Remove spaces from file names
    [BeagleV-FIRE_REV-A_230911.DSN]
2023-09-28 Remove spaces from files name
    [BeagleV-FIRE_REV-A_230911-1-12.drl]
2023-09-28 Change file name
    Removed the version number from the schematic.
2023-09-28 Update README
    Add board introduction and links.
2023-10-09 Update schematic
    All wrong labels in the schematic are not ajusted as per MPS025 pin names.
2023-10-11 Add pin assignment table
    [MPFS025T-FCVG484_Pin_Assignment.xlsx]
2023-10-18 Rev A board design files (without logo and name)
    [BeagleV-FIRE_REV-A_230911.DSN, art_param.txt, nc_param.txt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]
2023-11-08 Add BOM file
    [BeagleV-Fire_BOM.csv]
